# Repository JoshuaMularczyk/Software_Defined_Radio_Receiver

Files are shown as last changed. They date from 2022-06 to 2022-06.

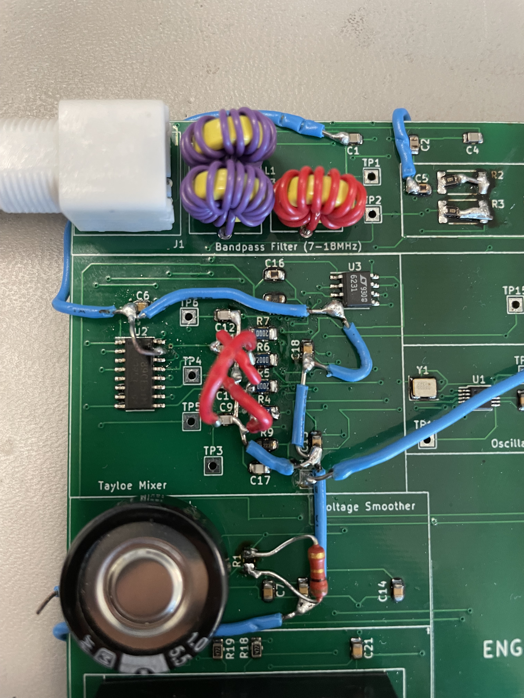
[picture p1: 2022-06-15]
Visuals/IMG-2089.jpg

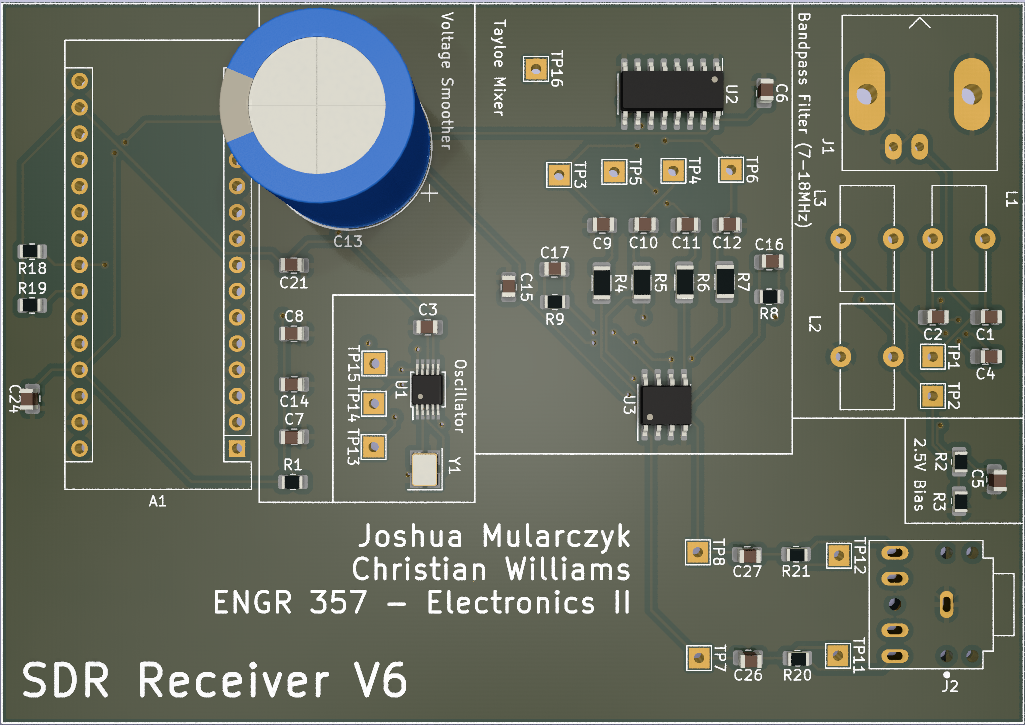
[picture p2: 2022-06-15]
Visuals/rev6pcb.PNG

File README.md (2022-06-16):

# Software-Defined-Radio-Reciever

This project was taken on with the goal to create a Software Defined Radio (SDR) in coolaboration with my partner [Christian Williams](https://github.com/cwill713). This project was completed for my Engineering Electronics II class and given to us by our professor, [Dr. Rob Frohne](https://github.com/frohro).

## Design Specifications/Objectives

These are the design specifications and objectives that my partner and I decided on. Origianlly, we decided to build a commercial FM radio, but after discusstion with Dr. Frohne, we reconsidered. The final specifications we decided on are as follows:

#### Objectives

- $25 budget
- Less than -107 dBm (1uV) minimum discernible signal
- *Stretch Goal* -127 dBm (.1uV) minimum discernible signal
- Good image rejection
- Low noise figure

#### Specs

- Frequency Range: 7MHz - 18MHz
- Radio Type: Shortwave
- One Butterworth Bandpass Filter
- One Tayloe Mixer
- One Bessel Lowpass Filter
- One Power Supply Noise Filter

## Overview

Our (SDR) receiver connects to an antenna (mounted ontop of the Engineering Building) and covers the filtering, mixing, and amplifying of the desired I and Q signals. Our I and Q signals are then passed through an external sound card and software handles the demodulation of the signal into audio. The mixing in our SDR is handled using an Arduino Nano running code provided to us by Dr. Rob Frohne which can be found in the [Arduino file](https://github.com/JoshuaMularczyk/Software_Defined_Radio_Receiver/blob/main/Arduino/New_Quisk_Nano/New_Quisk_Nano.ino). The Arduino interfaces with Quisk, an SDR that controls our receiver through the Arduino. Using Quisk, the radio can be tuned to a certain frequency by adjusting the speed of the local oscillator used in the mixing process.

## Theory

blockdia

The block diagram above shows the basic components of our SDR Receiver. The signal is received by an antenna and is passed through the bandpass filter which attenuates signals that are above or below our frequency range of 7-18 MHz. These signals are then passed through the Tayloe Quadrature Product Detector. This generates the I and Q signals for demodulation. Once the signals have been split they pass through the low noise filter which cuts off anything above 100 KHz, creating a smooth output signal. This signal is then send into an external soundcard which demodulates teh signal before it is read by Quisk software. Quisk interfaces to the Arduino Nana and allows for tuning of the desired frequency.

## Rev 6 Schematic

completeschematic

Christian and I built and tested our SDR based on the 5th Rev of this project. These schematics can be found in the Rev 5 file. The follow schematics are our most updated designs. These were created after finding multiple errors while constructing our pcb. The Rev 6 schematics can be downloaded [here](https://github.com/JoshuaMularczyk/Software_Defined_Radio_Receiver/tree/main/Schematics/SDRrecV6). These schematics were all designed in [KiCad](https://www.kicad.org/) and will be broken down into seperate pieces below.

### BandPass Filter

BandPass Filter and Voltage Divider

We built this bandpass filter using the [LC Filter Design Tool](https://rf-tools.com/lc-filter/.). This is a 3rd-Order Conventional, Series First, Butterworth Filter that will only allow frequencies between 7MHz and 18MHz to pass through it. It has input and output impedances of 50 ohms.

### Mixer and Lowpass Filter

Tayloe Mixer

The mixer that Christian and I decided to use was  Tayloe Mixer we referenced this [paper](http://www.norcalqrp.org/files/Tayloe_mixer_x3a.pdf) by Dan Tayloe when designing our mixer. The demultiplexer that we used was the [SN74CBT](http://www.ti.com/lit/gpn/sn74cbt3253) which converts the RF signal into four baseband signals. The Tayloe mixer uses switches to combine the signals that are 180 degrees out of phase with differential amplifiers so that signals above and below the oscilator frequecy can be detected.

Our Lowpass filter was designed using the [TI Filter Design Tool](). It was made using two [LT6231](https://www.analog.com/media/en/technical-documentation/data-sheets/623012fc.pdf) low noise op amps and is designed to block all frequencies greater that 100kHz.

### Voltage Smoother

Voltage Smoother

Our Voltage Smoother with take the 5V Vcc and remove as much noise as possible using a very large capacitace. Our schematic here shows the C3 having a value of 8200uF, however we ended up using a 1F capacitor that we already had in the lab. This takes the voltage that comes in from the computer and outputs a smoother 5V for the SDR to use.

### Arduino and Si5351

Arduino and Si5351

Our [Si5351](https://www.silabs.com/documents/public/data-sheets/Si5351-B.pdf) programmable oscillator allows us to input two clock signals that are 90 degrees out of phase into S0 and S1 of the SN74CBT3253. The Arduino Nano controls the frequency that is put out by the Si5351 for tuning. For our testing we had the [Aduino](http://www.mouser.com/pdfdocs/Gravitech_Arduino_Nano3_0.pdf) set the frequency to 14,190,000 Hz to match what was being output by a signal generator.

## Rev 5 Simulations

We conducted all of our simulations on [LTSpice](https://www.analog.com/en/design-center/design-tools-and-calculators/ltspice-simulator.html). My partner, Christian Williams, conducted the simulations of both filters and the Tayloe Mixer.

### Bandpass Filter

Bandpass Filter Simulation Graph
Bandpass Filter Simulation

Our Bandpass Filter was designed to allow a frequency range of 7-18MHz to pass through. As seen in the simulation above, curser 1 and cursor 2 mark the two freqency cutoff points. Inbetween them is the peak of our curve which is just where we want it.

### Lowpass Filter

LowPass Filter Simulation
LowPass Filter Schematic

### Complete SDR

Complete Simulation Graph
Complete SDR Simulation

We designed the tayloe mixer using four voltage controlled switches, and four voltage pulses that control them. For our op amps, we added our LT6231, these are already Linear Technology componenets so they dont take long to simulate in LTSpice. The LT6231's had a much lower noise profile than the LM4578's we selected for our second LPF(which we ended up removing in Rev 6), so we knew that the first LPF would take care of mostly everything and the second would just perfect the output. In the simulation window above you can see the baseband signals and the I and Q outputs. They're exactly as expected, about 90 degrees out of phase.

## Rev 6 PCB Design

rev6pcb

## Rev 5 Testing and Fixed Issues

When constructing our Rev 5 board, I ran into three issues. These issues have been fixed and closed. They are explained in detail in the issues page [here](https://github.com/JoshuaMularczyk/Software_Defined_Radio_Receiver/issues?q=is%3Aissue+is%3Aclosed)!

Luckily I was able to fix all of these mistakes with simple cutting and jumping techniques. We immediately fixed the schematics and Christian created Rev 6 of the PCB which was displayed above.

## Project Results

We first tested to see the minimum discernible signal by hooking our board up to a signal generator, our system running quisk software, and a soundcard. We adjusted the attenuator on the signal generator to output a signal of 14.19 MHz and then dropped the signal on the attenuator to see how small of a signal we could detect. In the image below, we see our radio has a minimum disernable signal of inbetween 0.3-0.4 uV!

minDecV2

We then hooked up our SDR to a BNC connector that ran to the roof of our Engineering building into an antenna. The final test was to see if we could hear any radio opperators transmitting around the world. We first looked at the signals being read in to see that our radio was picking up signals as far as Russia and Italy. Next we decided to listen in and found several bandwidths being used for communications. Here are two that we took snippets of.

The first signal that we tuned into was being used to communicate the weather from what sounded like an air traffic control tower. 

## "Wind 360 degrees, light drizzle, visibility more than 6 miles".

weather

The second was an automated message that would read off the Coordinated Universal time every minute.

## "At the tone ****** 5 hours 52 minutes coordinated universal time"

listeningIn

We were also able to listen to a few different music stations as well as two men in Hawaii talk about hurricanes to each other.

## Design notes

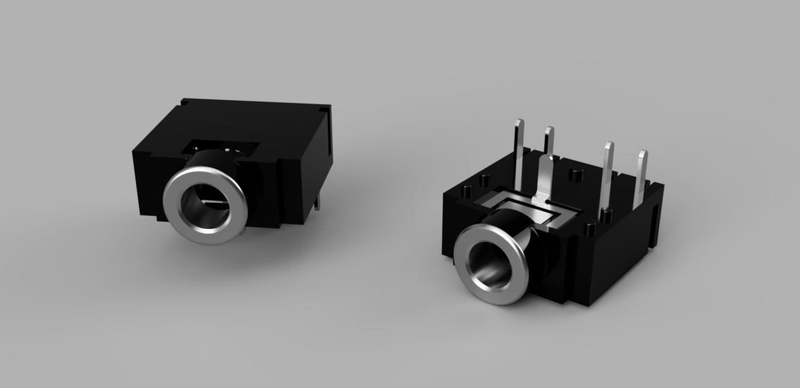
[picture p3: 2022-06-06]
Schematics/Audio Jack_Stereo 3.5mm/Audio_Jack1.png

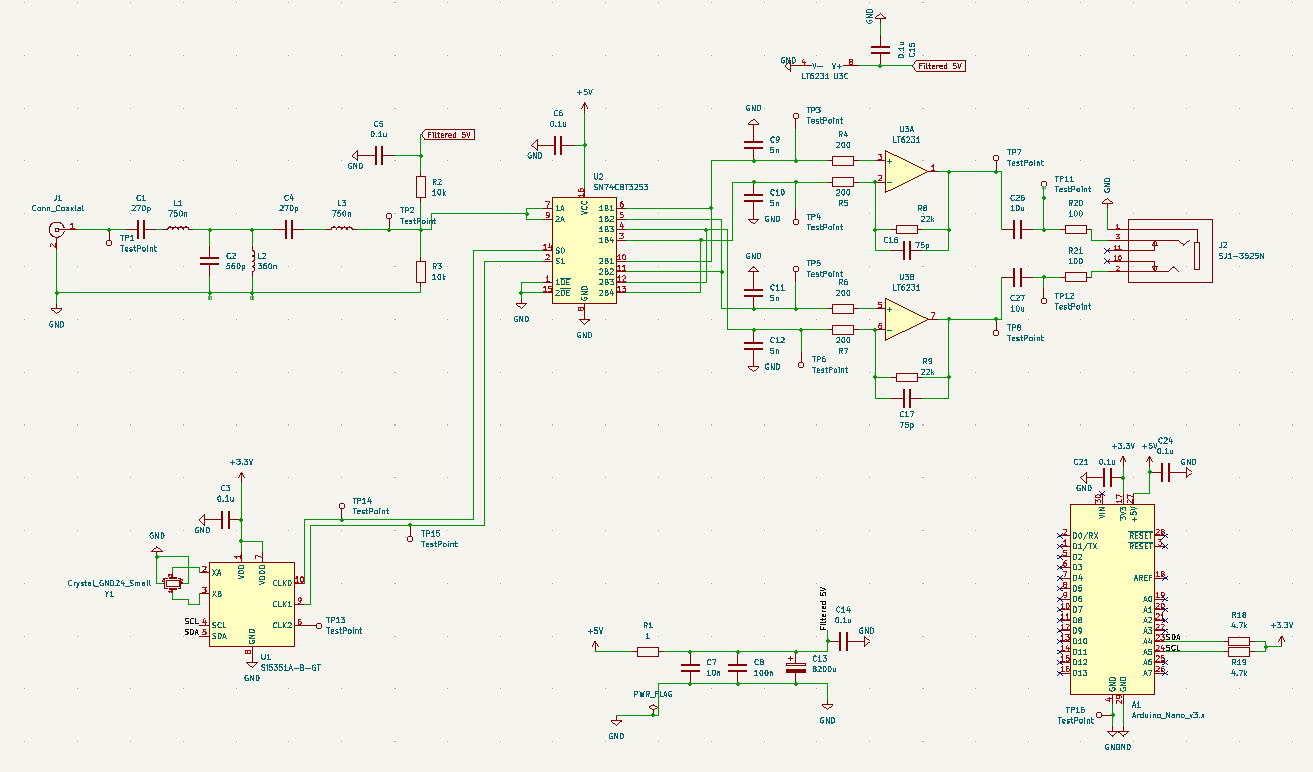
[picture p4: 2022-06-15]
Visuals/completeschematic.PNG

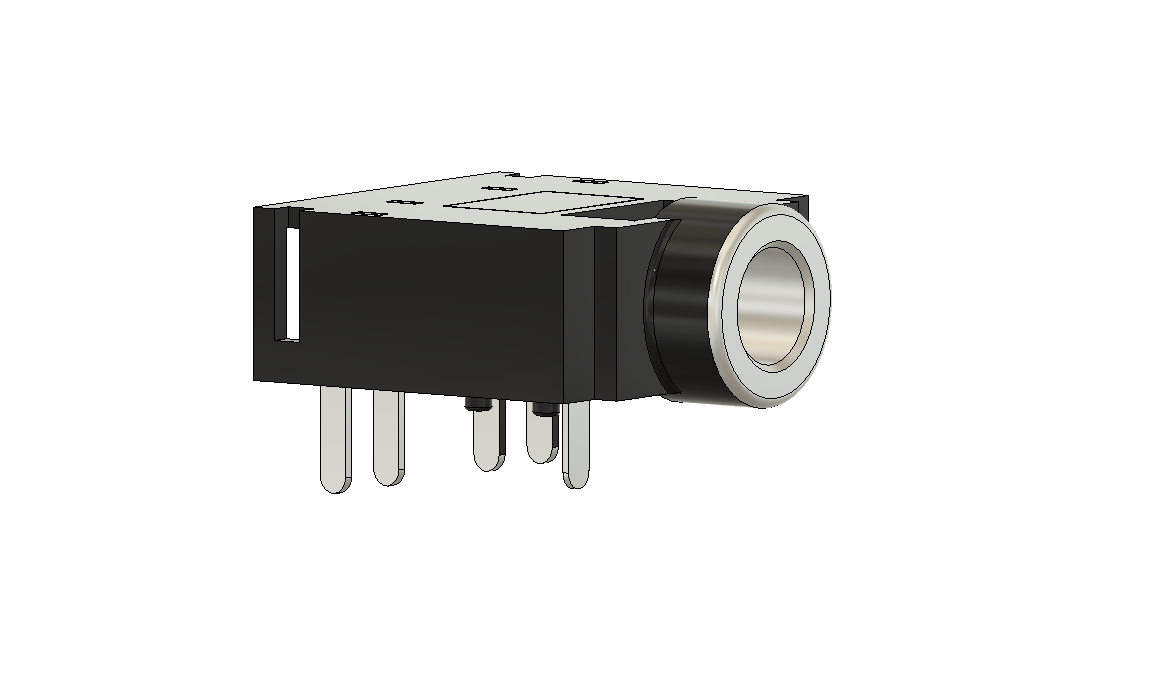
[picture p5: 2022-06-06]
Schematics/Audio Jack_Stereo 3.5mm/Audio_Jack2.png

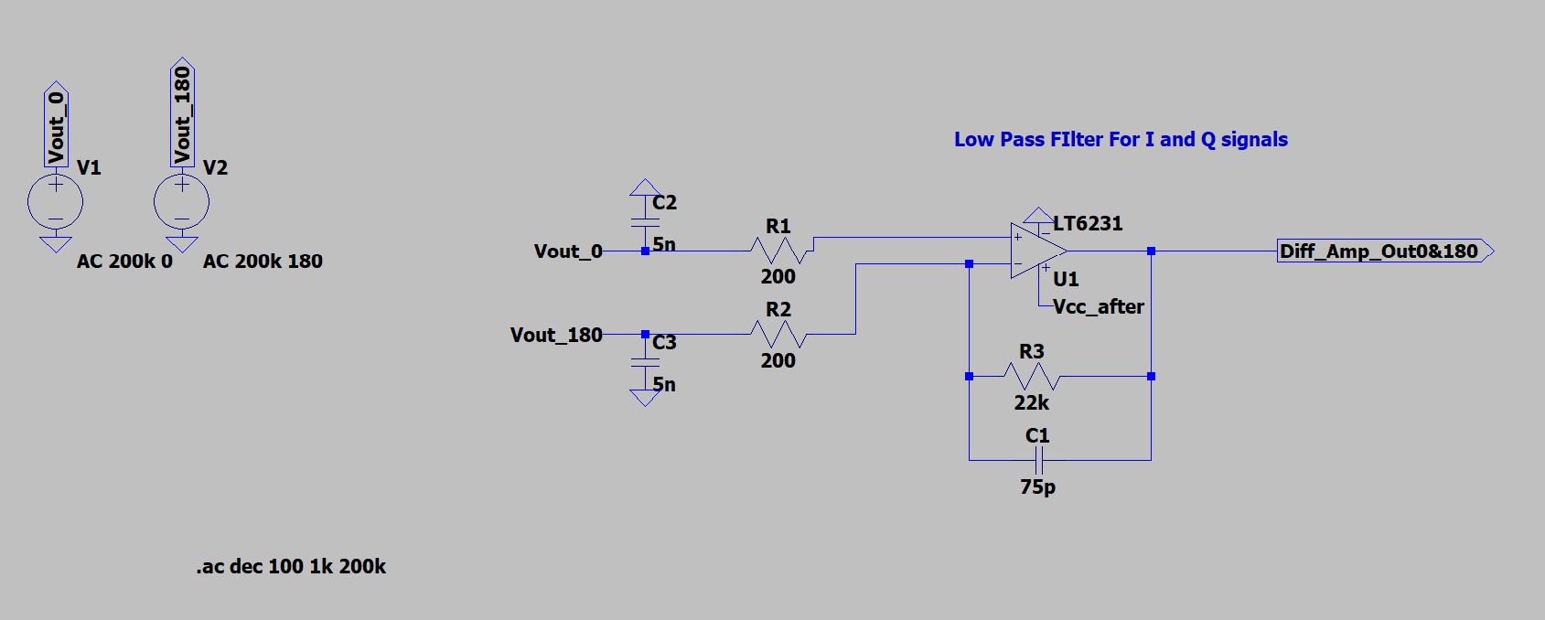
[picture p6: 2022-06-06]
Visuals/LowPass Filter Schematic.jpg

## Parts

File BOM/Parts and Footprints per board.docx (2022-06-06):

Parts and Footprints per board

2 10k Ohm resistor https://www.digikey.com/en/products/detail/cal-chip-electronics-inc/RM25J103CT/13569104 | 2512 packaging
2 270pF Capacitors https://www.digikey.com/en/products/detail/panasonic-electronic-components/ECH-U1H271GX5/353662 | Capacitor_SMD:C_0805_2012Metric
2 750nH Inductor https://www.digikey.com/en/products/detail/te-connectivity-passive-product/36502AR75JTDG/5399630 | 0805 packaging
1 560pF Capacitor https://www.digikey.com/en/products/detail/panasonic-electronic-components/ECH-U1H561GX5/353666 | Capacitor_SMD:C_0805_2012Metric
1 360nH Inductor https://www.digikey.com/en/products/detail/te-connectivity-passive-product/36502AR36JTDG/5399627 | 0805 packaging
9 .1uF Capacitors https://www.digikey.com/en/products/detail/cornell-dubilier-electronics-cde/FCA0805C104M-J2/1924083 | Capacitor_SMD:C_0805_2012Metric
1 SN74CBT3253D https://www.digikey.com/en/products/detail/texas-instruments/SN74CBT3253D/377929 | SOIC-16_3.9x9.9mm
4 5n Capacitors https://www.digikey.com/en/products/detail/murata-electronics/GRM2195C1H512JA01D/586786 | Capacitor_SMD:C_0805_2012Metric
4 200 Ohm Resistors https://www.digikey.com/en/products/detail/koa-speer-electronics-inc/RK73G2BTTD2000D/13590332 | Resistor_SMD:R_1206_3216Metric
2 22k Ohm Resistor https://www.digikey.com/en/products/detail/te-connectivity-passive-product/CRG0805F22K/2380871 | Resistor_SMD:R_0805_2012Metric
2 75pf Capacitors https://www.mouser.com/ProductDetail/Kyocera-AVX/08055A750FAT2A?qs=PcWMbIuZCschK4TeXNjJGQ%3D%3D | Capacitor_SMD:C_0805_2012Metric
2 4.64k Resistors https://www.digikey.com/en/products/detail/panasonic-electronic-components/ERJ-6ENF4641V/93079 | 0805
2 52.3k Resistors https://www.digikey.com/en/products/detail/stackpole-electronics-inc/RNCP0805FTD52K3/2240287 | Resistor_SMD:R_0805_2012Metric
4 100 pf Capacitors https://www.digikey.com/en/products/detail/panasonic-electronic-components/ECH-U1H101GX5/353657 | Capacitor_SMD:C_0805_2012Metric
2 2.49k Ohm Resistors https://www.digikey.com/en/products/detail/koa-speer-electronics-inc/RK73G2ATTD2491F/13575866 | Resistor_SMD:R_0805_2012Metric
2 17.4k Ohm Resistors https://www.digikey.com/en/products/detail/panasonic-electronic-components/ERA-6AEB1742V/2025773 | Resistor_SMD:R_0603_1608Metric
2 10uF Capacitors https://www.digikey.com/en/products/detail/samsung-electro-mechanics/CL21A106KOQNNNG/3894417 | Capacitor_SMD:C_0805_2012Metric
2 100 Ohm Resistors https://www.digikey.com/en/products/detail/koa-speer-electronics-inc/RK73G2ATTD1000D/13576043 | Resistor_SMD:R_0805_2012Metric
2 4.7k Ohm Resistors https://www.digikey.com/en/products/detail/te-connectivity-passive-product/CRGCQ0805J4K7/8576740 | Resistor_SMD:R_0805_2012Metric
1 10nF Capacitor https://www.digikey.com/en/products/detail/cornell-dubilier-electronics-cde/FCP0805C103J-J2/1924307 | Capacitor_SMD:C_0805_2012Metric
1 100nF Capacitor https://www.digikey.com/en/products/detail/cornell-dubilier-electronics-cde/FCA0805C104M-J2/1924083 | Capacitor_SMD:C_0805_2012Metric
1 10uF Polarized Capacitor https://www.digikey.com/en/products/detail/panasonic-electronic-components/EEE-FK1C100R/765952 | lmao:CAP_EEEFK1C100R
1 25MHz Crystal https://www.digikey.com/en/products/detail/kyocera-avx/CX3225SB25000D0FLJCC/6123311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 | Crystal:Crystal_SMD_3225-4Pin_3.2x2.5mm

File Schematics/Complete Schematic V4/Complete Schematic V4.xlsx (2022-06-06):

Source: | C:\Users\willi\OneDrive\Documents\Walla Walla University\Spring 2022\Electronics II\SDR GitHub\Schematic\Complete Schematic V4\Complete Schematic V4.kicad_sch
Date: | 2022-04-28 00:24
Tool: | Eeschema (6.0.4)
Generator: | C:\Program Files\KiCad\6.0\bin\scripting\plugins/bom_csv_grouped_by_value_with_fp.py
Component Count: | 73
Ref | Qnty | Value | Cmp name | Footprint | Description | Vendor
A1, | 1 | Arduino_Nano_v3.x | Arduino_Nano_v3.x | Module:Arduino_Nano | Arduino Nano v3.x
C1, C4, | 2 | 270p | C | Capacitor_SMD:C_0805_2012Metric | Unpolarized capacitor
C2, | 1 | 560p | C | Capacitor_SMD:C_0805_2012Metric | Unpolarized capacitor
C3, C5, C6, C14, C15, C18, C21, C24, C25, | 9 | 0.1u | C | Capacitor_SMD:C_0805_2012Metric | Unpolarized capacitor
C7, | 1 | 10n | C | Capacitor_SMD:C_0805_2012Metric | Unpolarized capacitor
C8, | 1 | 100n | C | Capacitor_SMD:C_0805_2012Metric | Unpolarized capacitor
C9, C10, C11, C12, | 4 | 5n | C | Capacitor_SMD:C_0805_2012Metric | Unpolarized capacitor
C13, | 1 | EEEFK1C100R | EEEFK1C100R | lmao:CAP_EEEFK1C100R
C16, C17, | 2 | 75p | C | Capacitor_SMD:C_0805_2012Metric | Unpolarized capacitor
C19, C20, C22, C23, | 4 | 100p | C | Capacitor_SMD:C_0805_2012Metric | Unpolarized capacitor
C26, C27, | 2 | 10u | C | Capacitor_SMD:C_0805_2012Metric | Unpolarized capacitor
J1, | 1 | Conn_Coaxial | Conn_Coaxial | Connector_Coaxial:BNC_Amphenol_B6252HB-NPP3G-50_Horizontal | coaxial connector (BNC, SMA, SMB, SMC, Cinch/RCA, LEMO, ...)
J2, | 1 | USB_A | USB_A | Connector_USB:USB_A_Molex_67643_Horizontal | USB Type A connector
J3, | 1 | AudioJack3 | AudioJack3 | Connector_Audio:Jack_3.5mm_CUI_SJ-3523-SMT_Horizontal | Audio Jack, 3 Poles (Stereo / TRS)
L1, L3, | 2 | 750n | L | Inductor_SMD:L_0805_2012Metric | Inductor
L2, | 1 | 360n | L | Inductor_SMD:L_0805_2012Metric | Inductor
R2, R3, | 2 | 10k | R | Resistor_SMD:R_2512_6332Metric | Resistor
R4, R5, R6, R7, | 4 | 200 | R | Resistor_SMD:R_1206_3216Metric | Resistor
R8, R9, | 2 | 22k | R | Resistor_SMD:R_2512_6332Metric | Resistor
R10, R11, | 2 | 4.64k | R | Resistor_SMD:R_0805_2012Metric | Resistor
R12, R13, | 2 | 52.3k | R | Resistor_SMD:R_0805_2012Metric | Resistor
R14, R15, | 2 | 2.49k | R | Resistor_SMD:R_0805_2012Metric | Resistor
R16, R17, | 2 | 17.4k | R | Resistor_SMD:R_0805_2012Metric | Resistor
R18, R19, | 2 | 4.7k | R | Resistor_SMD:R_0805_2012Metric | Resistor
R20, R21, | 2 | 100 | R | Resistor_SMD:R_0805_2012Metric | Resistor
TP1, TP2, TP3, TP4, TP5, TP6, TP7, TP8, TP9, TP10, TP11, TP12, | 12 | TestPoint | TestPoint |  | test point
U1, | 1 | Si5351A-B-GT | Si5351A-B-GT | Package_SO:MSOP-10_3x3mm_P0.5mm | I2C Programmable Any-Frequency CMOS Clock Generator, MSOP-8
U2, | 1 | SN74CBT3253 | SN74CBT3253 | Package_SO:SOIC-16_3.9x9.9mm_P1.27mm | Dual 1 to 4 Analog Multiplexer
U3, U4, | 2 | LT6231 | OPAMP | Package_SO:SOIC-8_3.9x4.9mm_P1.27mm | OPAmp symbol for simulation only
U5, U6, | 2 | LM4562MA | OPAMP | Package_SO:SOIC-8_3.9x4.9mm_P1.27mm | OPAmp symbol for simulation only
Y1, | 1 | Crystal | Crystal |  | Two pin crystal

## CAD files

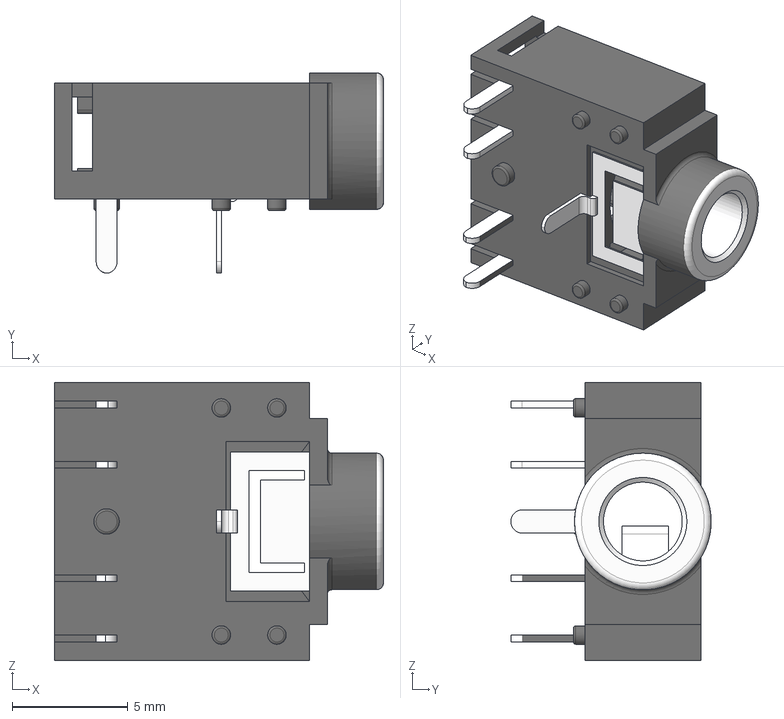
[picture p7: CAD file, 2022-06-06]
Schematics/Audio Jack_Stereo 3.5mm/Audio Jack.step
14.2 x 8.65 x 12.0 mm

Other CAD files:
Schematics/Audio Jack_Stereo 3.5mm/Audio Jack.f3d

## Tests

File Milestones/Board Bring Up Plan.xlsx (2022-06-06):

Build and Test Plan | Testers: Joshua Mularczyk and Christian Williams
Steps: | Description: | Column3 | Column4 | Column5 | Column6 | Column7 | Column8 | Column9 | Column10 | Column11 | Column12
1 | Unbox Parts/PCB and take inventory
2 | Solder everything onto pcb
3 | Test bandpass filter by using signal generator and using initial windings on inductors. Keep adjusting windings until only 7-18MHz pass through
4 | Test Clocks by putting the oscilloscope across the clock test point and ground. Program the clock to what it needs to be and measure the frequency. Make sure there is a 90 degreee phase shift.
5 | Test the 4 points outputted from the Tayloe Mixer and make sure the top two inputs are 180 degrees apart and the bottom two are 180 degrees apart.
6 | Use the test point at the output of the second lowpass filter to make sure that only 100 KHz are entering the soundcard.
7 | After these main tests, check each test point to make sure values correspond with the simulated or expected values.
8 | Run the program and see if everything works
9 | Once the SDR is working with the signal generator, take the SDR up and connect it to the antenna.
10

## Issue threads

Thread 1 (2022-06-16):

Missing ground plane on Rev 5 pcb

JoshuaMularczyk, 2022-06-16:
When our Rev 5 boards arrived we realized that there was no ground plane. I had accidentally clicked off the ground plane right before generating the Gerber files, so no ground plane was present. To fix this, I went ahead and connected any ground connections that relied on the ground plane with external wires. This can be seen in the [Rev 5 photos on the wiki](https://github.com/JoshuaMularczyk/Software_Defined_Radio_Receiver/wiki/Rev-5-Photos).

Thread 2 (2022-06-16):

Tayloe Mixer connection (wrong order)

JoshuaMularczyk, 2022-06-16:
Next, a fellow classmate, [Nicholas Zimmerman](https://github.com/nickz12345), who had been helping us error check, noticed that we had wired our Tayloe Mixer incorrectly. We had connected our outputs across to the amplifiers in ascending order (1,2,3,4) when they were actually supposed to be connected in the following order (1,4,2,3). I then cut the last three out of the four traces and jumped the wires to send the I and Q signals to the correct paths. This can also be seen in the [wiki](https://github.com/JoshuaMularczyk/Software_Defined_Radio_Receiver/wiki/Rev-5-Photos).

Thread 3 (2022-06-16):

Second Low Pass Filter Error

JoshuaMularczyk, 2022-06-16:
This error was for our Rev 5 design and was found in our second low pass filter. This was discovered by [Dr. Rob Frohne](). We had not realized that the V- needed to be connected to a negative voltage instead of ground. Luckily this was a backup filter and most of the gain was in our first LPF. To fix this, I simply just removed the second LPF from the board and jumped the outputs of the first LPF to the inputs of the capacitors right before our audio connector.

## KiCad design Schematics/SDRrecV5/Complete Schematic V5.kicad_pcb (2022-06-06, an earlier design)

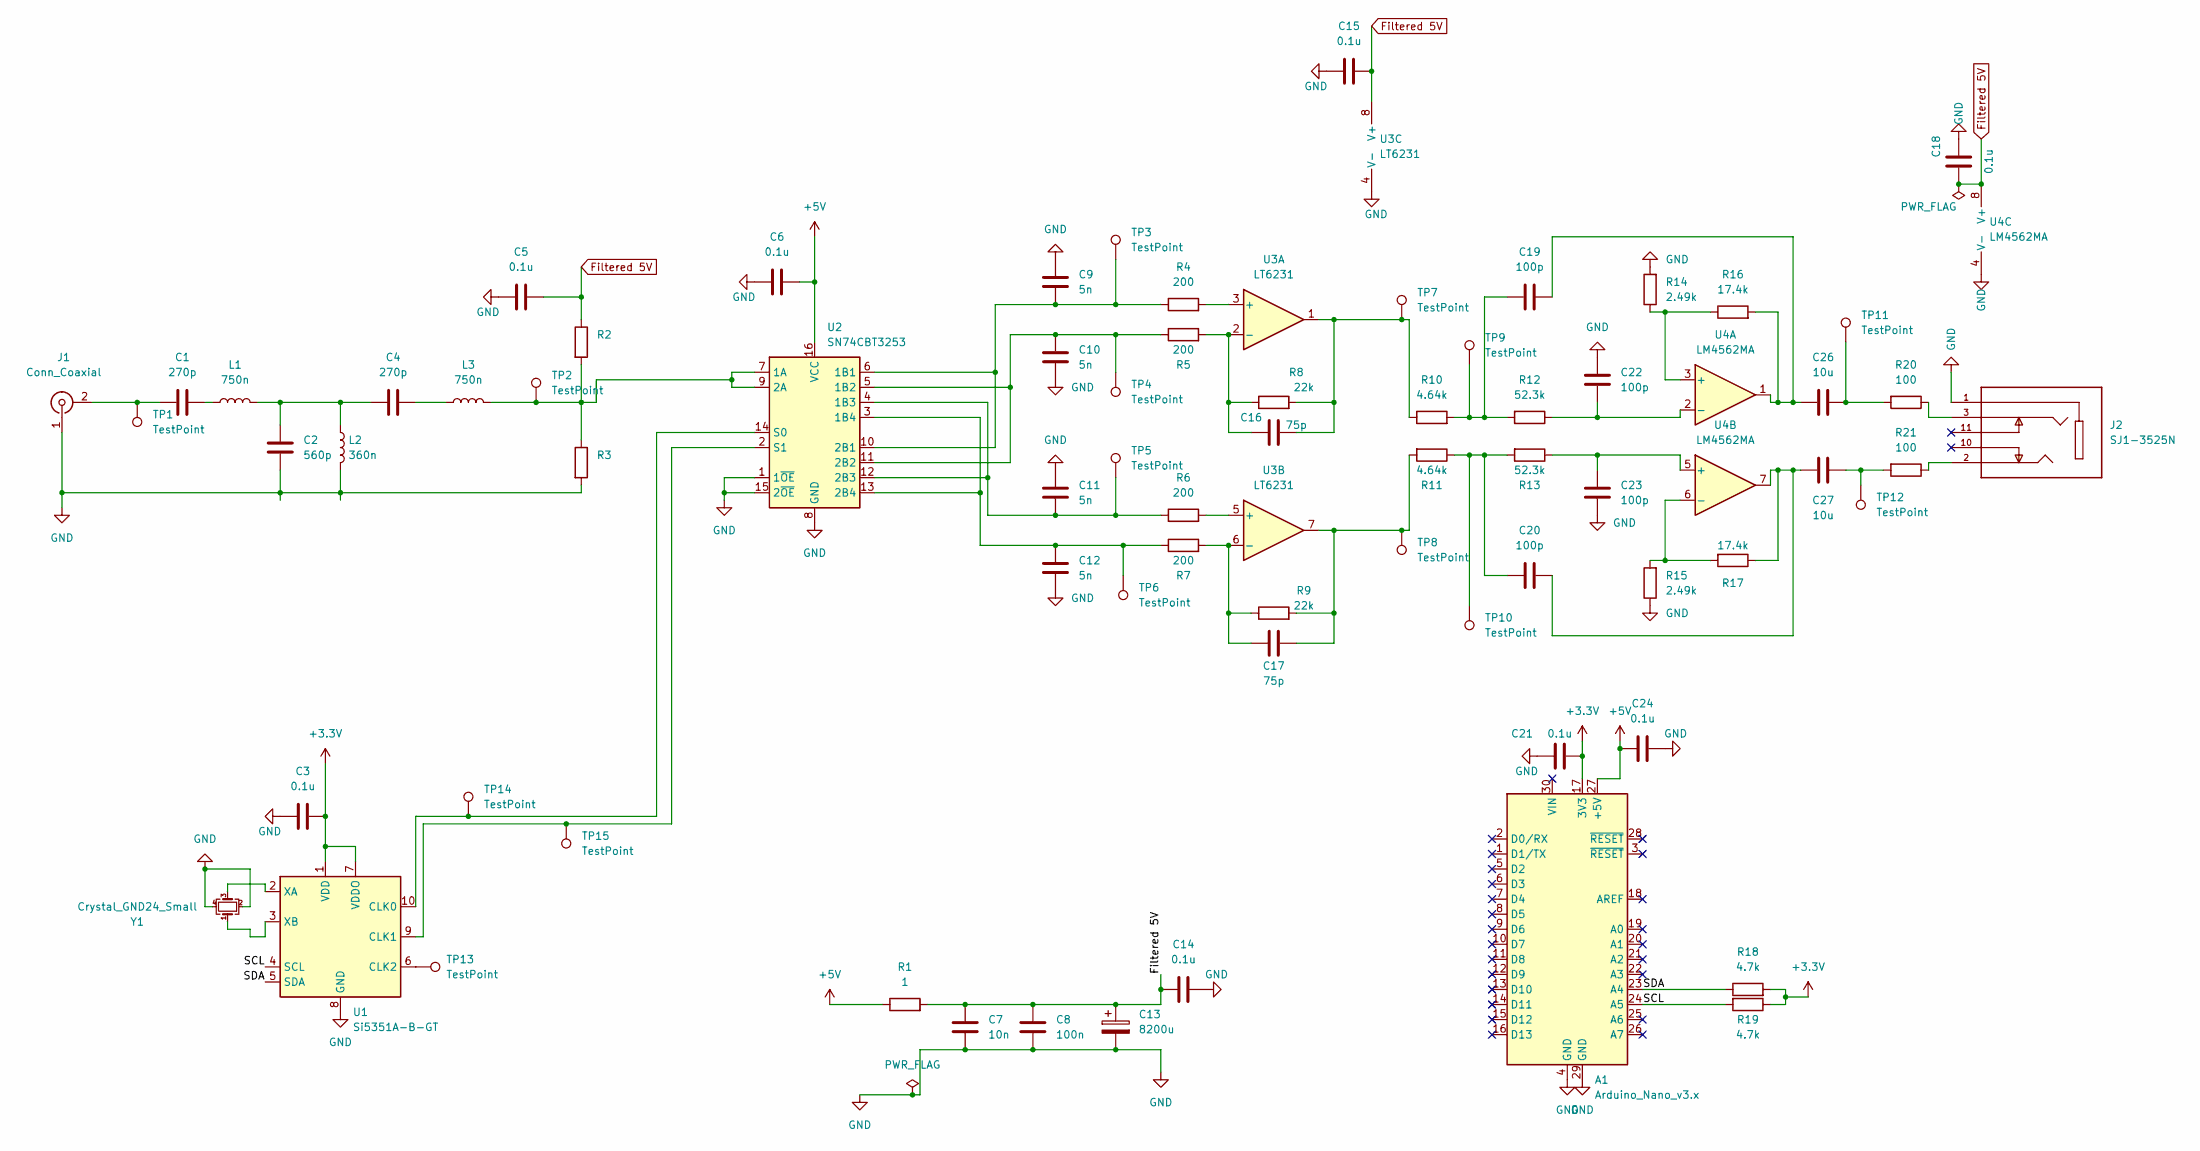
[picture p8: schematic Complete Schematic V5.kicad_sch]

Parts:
A1: Arduino_Nano_v3.x; Arduino_Nano
C1, C4: 270p; C_0805_2012Metric
C2: 560p; C_0805_2012Metric
C3, C5, C6, C14, C15, C18, C21, C24: 0.1u; C_0805_2012Metric
C7: 10n; C_0805_2012Metric
C8: 100n; C_0805_2012Metric
C9, C10, C11, C12: 5n; C_0805_2012Metric
C13: 8200u; CP_Radial_D16.0mm_P7.50mm
C16, C17: 75p; C_0805_2012Metric
C19, C20, C22, C23: 100p; C_0805_2012Metric
C26, C27: 10u; C_0805_2012Metric
J1: Conn_Coaxial; BNC_Amphenol_B6252HB-NPP3G-50_Horizontal
J2: SJ1-3525N; Jack_3.5mm_stereo_TRS_jack; PARTREV 1.02
L1, L3: 750n; L_Toroid_Vertical_L10.0mm_W5.0mm_P5.08mm
L2: 360n; L_Toroid_Vertical_L10.0mm_W5.0mm_P5.08mm
R1: 1; R_0805_2012Metric
R2, R3: (no value)
R4, R5, R6, R7: 200; R_1206_3216Metric
R8, R9: 22k; R_0805_2012Metric
R10, R11: 4.64k; R_0805_2012Metric
R12, R13: 52.3k; R_0805_2012Metric
R14, R15: 2.49k; R_0805_2012Metric
R16, R17: 17.4k; R_0805_2012Metric
R18, R19: 4.7k; R_0805_2012Metric
R20, R21: 100; R_0805_2012Metric
TP1, TP2, TP3, TP4, TP5, TP6, TP7, TP8, TP9, TP10, TP11, TP12, TP13, TP14, TP15: TestPoint; TestPoint_THTPad_2.0x2.0mm_Drill1.0mm
U1: Si5351A-B-GT; MSOP-10_3x3mm_P0.5mm
U2: SN74CBT3253; SOIC-16_3.9x9.9mm_P1.27mm
U3: LT6231; SOIC-8_3.9x4.9mm_P1.27mm
U4: LM4562MA; SOIC-8_3.9x4.9mm_P1.27mm
Y1: Crystal_GND24_Small; Crystal_SMD_3225-4Pin_3.2x2.5mm

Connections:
+3V3: A1.17 (3V3), C3.2, C21.2, R18.2, R19.1, U1.1 (VDD), U1.7 (VDDO)
+5V: A1.27 (+5V), C6.2, C24.2, R1.1, U2.16 (VCC)
/SCL: A1.24 (A5), R19.2, U1.4 (SCL)
/SDA: A1.23 (A4), R18.1, U1.5 (SDA)
Filtered 5V: C5.2, C7.1, C8.1, C13.1, C14.2, C15.2, C18.2, R1.2, R2.1, U3.8 (V+), U4.8 (V+); also elsewhere on the board
GND: A1.4 (GND), A1.29 (GND), C2.2, C3.1, C5.1, C6.1, C7.2, C8.2, C9.2, C10.1, C11.2, C12.1, C13.2, C14.1, C15.1, C18.1, C21.1, C22.2, C23.1, C24.1, J1.1 (In), J2.1, L2.2, R3.2, R14.2, R15.1, U1.8 (GND), U2.1 (1~OE), U2.8 (GND), U2.15 (2~OE), U3.4 (V-), U4.4 (V-), Y1.2, Y1.4; also elsewhere on the board
unnamed: C1.1, L1.1
unnamed: C1.2, J1.2 (Ext), TP1.1
unnamed: C2.1, C4.1, L1.2, L2.1
unnamed: C4.2, L3.1
unnamed: C9.1, R4.1, TP3.1, U2.6 (1B1), U2.10 (2B1)
unnamed: C10.2, R5.1, TP4.1, U2.5 (1B2), U2.11 (2B2)
unnamed: C11.1, R6.1, TP5.1, U2.4 (1B3), U2.12 (2B3)
unnamed: C12.2, R7.1, TP6.1, U2.3 (1B4), U2.13 (2B4)
unnamed: C16.1, R8.2, R10.1, TP7.1, U3.1
unnamed: C16.2, R5.2, R8.1, U3.2 (-)
unnamed: C17.1, R9.2, R11.2, TP8.1, U3.7
unnamed: C17.2, R7.2, R9.1, U3.6 (-)
unnamed: C19.1, R10.2, R12.2, TP9.1
unnamed: C19.2, C26.2, R16.2, U4.1
unnamed: C20.1, R11.1, R13.2, TP10.1
unnamed: C20.2, C27.2, R17.1, U4.7
unnamed: C22.1, R12.1, U4.2 (-)
unnamed: C23.2, R13.1, U4.5 (+)
unnamed: C26.1, R20.2, TP11.1
unnamed: C27.1, R21.2, TP12.1
unnamed: J2.2, R21.1
unnamed: J2.3, R20.1
unnamed: L3.2, R2.2, R3.1, TP2.1, U2.7 (1A), U2.9 (2A)
unnamed: R4.2, U3.3 (+)
unnamed: R6.2, U3.5 (+)
unnamed: R14.1, R16.1, U4.3 (+)
unnamed: R15.2, R17.2, U4.6 (-)
unnamed: TP13.1, U1.6 (CLK2)
unnamed: TP14.1, U1.10 (CLK0), U2.14 (S0)
unnamed: TP15.1, U1.9 (CLK1), U2.2 (S1)
unnamed: U1.2 (XA), Y1.3
unnamed: U1.3 (XB), Y1.1

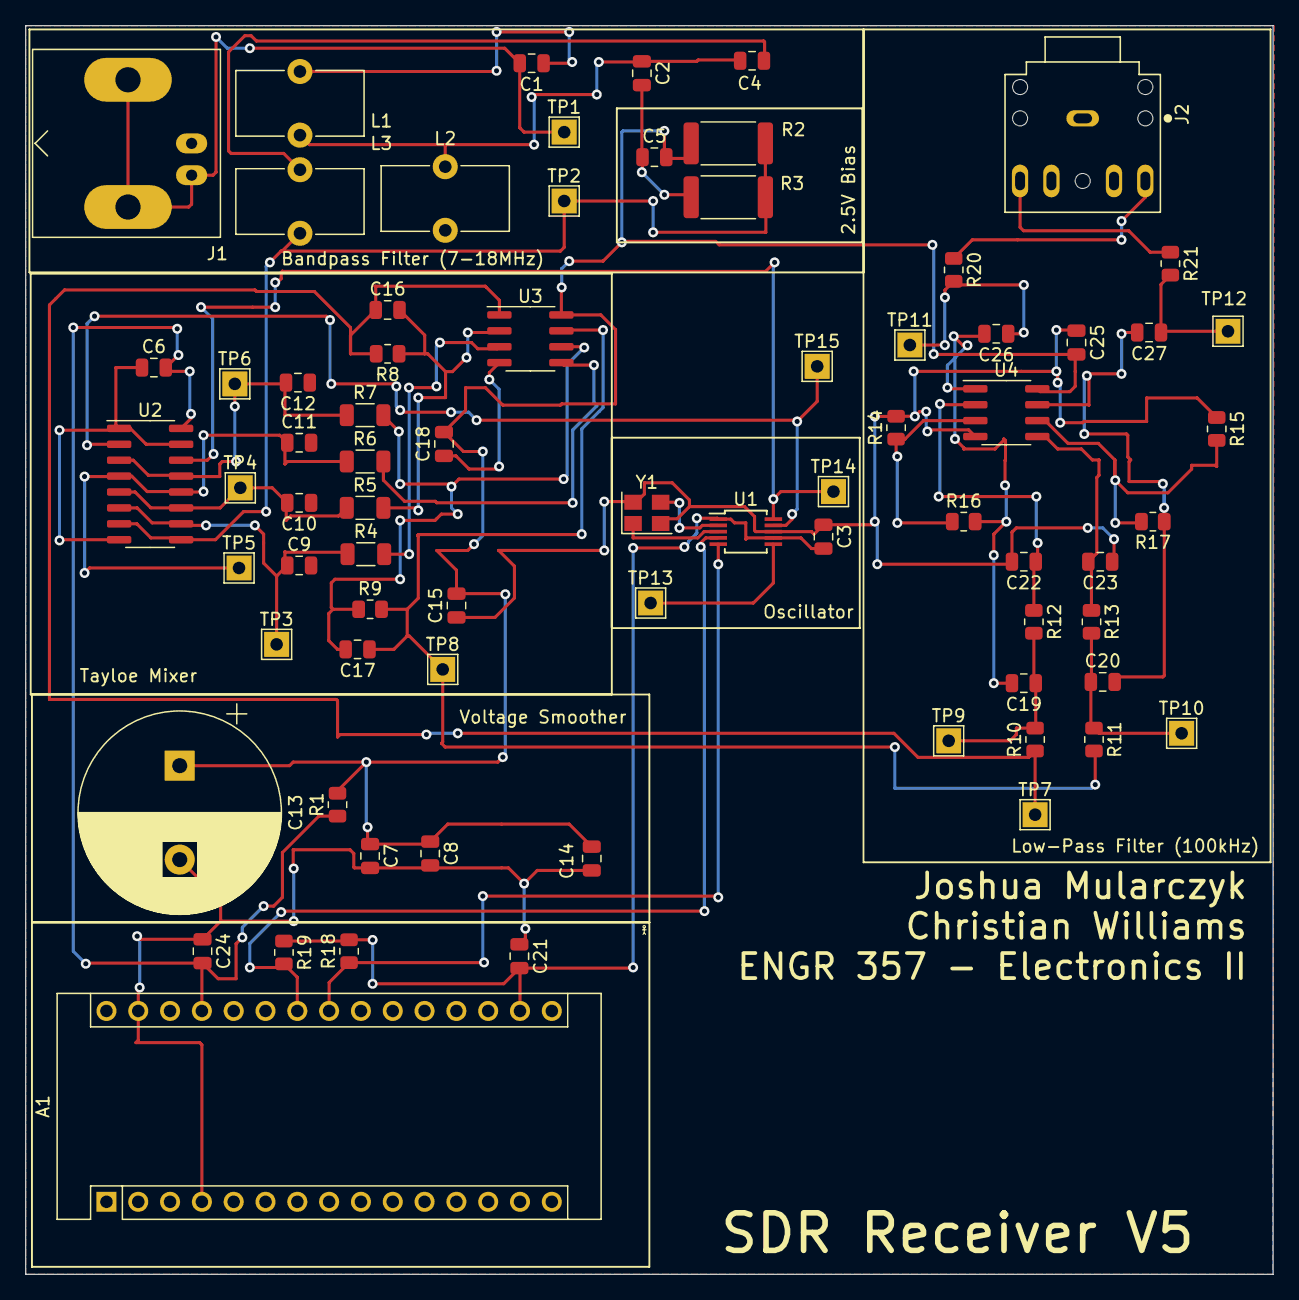
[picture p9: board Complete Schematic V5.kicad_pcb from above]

Board: 2 copper layers, 99.6 x 99.7 mm, 74 parts (0 on the bottom side), 38 nets.

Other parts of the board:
C25: 0.1u; C_0805_2012Metric

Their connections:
Filtered 5V: C25.2; also elsewhere on the board
GND: C25.1; also elsewhere on the board

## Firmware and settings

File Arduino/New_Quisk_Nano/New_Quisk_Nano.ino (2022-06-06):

#include <si5351.h>

#include <si5351.h>


/*
  OpenRadio Quisk Interface 
  Main
  This is used to provide a serial interface which Quisk SDR can talk to.
  
  Copyright (C) 2014 Mark Jessop <vk5qi@rfhead.net>

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
    For a full copy of the GNU General Public License, 
    see <http://www.gnu.org/licenses/>.

   Command Reference:
    ------------------
    All commands consist of an identifier, followed by one or more parameters delinieated by commas, then a newline.
    i.e.:
    COMMAND,<param1>,<param2><LF>
    
    A command will return OK<LF> if successful, and ERROR<LF> if not. Some commands (particuarly transmit commands)
    may take a significant amount of time to return.
    
    Sending a command which takes parameters, without sending the parameters, will return the set parameters.
    
    Frequency Settings:
    
    FREQ,<freq>     - Set the center freq of the receiver, in Hz.
    FREQPSK,<freq>    - Set the transmit frequency, in Hz.

    Modulation:
    All transmissions will time out after 10 minutes. (if we implement it)
    
    CARRIER,<ON/OFF>  - Transmit a carrier.
    PSK,<rate>,message  - Send message using Phase Shift Keying, with the specified symbol rate.

    This version is made for the Rasbperry Pi Pico using the MBED OS..
*/

#include <Arduino.h>

//#warning __PGMSPACE_H_

//#include <EEPROM.h>
#include <Wire.h>

#include "si5351.h"

#include "settings.h"
#include "pins.h"
//#include "ring_buffer.h"

#define VERSION "0.3"

// #define USE_JOHNSON_COUNTER
// Default output frequency
#define RX_FREQ 14200000
#define TX_FREQ 14200000
#define FREQ_LIMIT_LOWER 100000
#define FREQ_LIMIT_UPPER 30000000 

#define SERIAL_BAUD     57600

Si5351 si5351;

uint8_t si5351_init();
int parseFreq(String input);
int parseCarrier(String carrier_str);
int set_channel(String input);

int tx_relay_state = 0;
int tx_state = 0;

static struct settings settings;

// Ring buffer for use with the interrupt-driven transmit buffer.
//struct ring_buffer data_tx_buffer = { { 0 }, 0, 0};

/* Returns true if settings are valid */
//static bool read_settings(void)
//{
//    uint8_t *p = (uint8_t *)&settings;
//    int i = 0;
//
//    while(i < sizeof(struct settings))
//        *p++ = EEPROM.read(i++);
//
//    return settings.magic == SETTINGS_MAGIC;
//}

//static void write_settings(void)
//{
//    uint8_t *p = (uint8_t *)&settings;
//    int i = 0;
//
//    // Invalidate checksum to guard against partial writes
//    EEPROM.write(0, 0);
//
//    while(i < sizeof(struct settings))
//        EEPROM.write(i++, *p++);
//}

// Input buffer for reading user input.
#define INPUTBUFLEN 64
//char inputBuffer[INPUTBUFLEN];
int inputBufferPtr = 0;
char tempBuffer[20]; // Buffer for string to int conversion.
String inputBuffer = "";

void setup(){
    // Initialise things.
    pinMode(TX_RX_SWITCH, OUTPUT);
    digitalWrite(TX_RX_SWITCH, LOW);
    pinMode(MODULATION, OUTPUT);
    digitalWrite(MODULATION, LOW);
    pinMode(LED, OUTPUT);
    digitalWrite(LED, LOW);

    Serial.begin(SERIAL_BAUD);
    Serial.setTimeout(1000 * 10);

    uint8_t rev_id = si5351_init();

    // Click the relay as an 'audible' startup indicator.
    digitalWrite(TX_RX_SWITCH, HIGH);
    delay(300);
    digitalWrite(TX_RX_SWITCH, LOW);



// Perform Si5351 calibration
    uint64_t rx_freq = 1000024200ULL;  // Where you receive WWV before calibration...
    uint64_t target_freq = 1000000000ULL; // 10 MHz, in hundredths of hertz
    uint32_t cal_factor = (int32_t)(target_freq - rx_freq);
    si5351.set_correction(cal_factor, SI5351_PLL_INPUT_XO);
    si5351.set_pll(SI5351_PLL_FIXED, SI5351_PLLA);
    si5351.pll_reset(SI5351_PLLA);

   //    if (!read_settings()) {
        //Serial.println(F("Resetting settings to defaults"));
        settings.magic = SETTINGS_MAGIC;
        settings.rx_freq = RX_FREQ;
        settings.tx_freq = TX_FREQ;
        settings.cal_factor = cal_factor;
//    }
    
    set_rx_freq(settings.rx_freq);
    set_tx_freq(settings.tx_freq);
}

void loop(){
  if(Serial.available()){
    // Read in a byte.
    char inChar = (char)Serial.read();
    
    // Work out what the character is. If letters or numbers, add to
    // the buffer, if not, don't add.
    
    // If character is a newline, we have reached the end of the command.
    if( (inChar == '\n') || (inputBufferPtr>INPUTBUFLEN)){
      // Parse string
      if( parseCommand(inputBuffer)==0 ){
        Serial.println("OK");
      }else{
        Serial.println("ERROR");
      }
      inputBuffer = "";
      inputBufferPtr = 0;
    }else if( isalnum(inChar) || ispunct(inChar) || isblank(inChar) || inChar==4 ){
      // Add to the input buffer if printable and not a line ending.
      inputBuffer += inChar;
      inputBufferPtr++;
    }
  }
}

// CSV parser function. Splits input into arguments.
// I am so sorry...
int parseCommand(String input){
  int params = 0;
  
  if(input.length()<3){
    // No command is shorter than 3 characters. Error.
    return 1;
  }
  // At this point we have found some sort of command (maybe)
  

  // Search through for commas, populate an array of pointers, make pointer = -1 if nothing found.
  // NOTE: This is a horrible bit of code. If theres is a better way to do CSV parsing in Arduino, let me know!
  int separators[] = {-1,-1,-1,-1,-1,-1};

  separators[0] = input.indexOf(",");
  
  if(separators[0] != -1){ // If we find one comma, maybe there are more...
    int i = 1;
    while((separators[i-1] != -1) && i<6){
      params++;
      separators[i] = input.indexOf(",", separators[i-1]+1);
      i++;
    }
  
  }

  if(params==0){ // Either a request command or a command with no parameter
    if(input.startsWith("FREQPSK")){
      Serial.print("FREQPSK,"); Serial.println(settings.tx_freq);
      return 0;
    }else 
    if(input.startsWith("FREQ")){
      Serial.print("FREQ,"); Serial.println(settings.rx_freq);
      return 0;
    }else if(input.startsWith("CAL")){
      Serial.print("CAL,"); Serial.println(settings.cal_factor,10);
      return 0;
    }else if(input.startsWith("VER")){
      Serial.print("VER,"); Serial.println("OpenRadio V1.1");
      return 0;
    }else{
      // No other commands are valid without parameters. Error
      return 1;
    }
  }else if(params==1){ // Commands with one argument.
    String param1 = input.substring(separators[0]+1); // Extract the argument for passing to the function.
    if(input.startsWith("FREQPSK")){
//      return parsePSKFreq(param1);
    }else if(input.startsWith("FREQ")){
      return parseFreq(param1);
    }
    else if(input.startsWith("PSKFREQ")){
//      return parsePSKFreq(param1);
    }else if(input.startsWith("CARRIER")){
      return parseCarrier(param1);
    }else if(input.startsWith("CHAN")){
      return set_channel(param1);
    }else{
      // No other commands are valid with only one parameter. Error
      return 1;
    }
  }
//  else if(params==2){ // Commands with 2 parameters (PSK);
//    String param1 = input.substring(separators[0]+1, separators[1]);
//    String param2 = input.substring(separators[1]+1);
//    
//    if(input.startsWith("PSK")){
//      return psk_transmit(param1,param2);
//    }else{
//      // No other commands are valid with only one parameter. Error
//      return 1;
//    }
//  }

  return 1; // Cannot parse command, error.
}

int freqValid(uint32_t freq){
  return (freq>FREQ_LIMIT_LOWER) && (freq<FREQ_LIMIT_UPPER);
}

// Parse frequency, program radio.
int parseFreq(String input){
  unsigned long result = 0;
  unsigned long combinedresult = 0;
  char* endptr;
  
  input.toCharArray(tempBuffer,10);
  
  result = strtoul(tempBuffer,&endptr,10);
  // If strtoul fails to convert, *endptr contains the character which conversion failed on.
  // Otherwise, *endptr contains '\0'.
  if(*endptr != 0) return -1;
  
  if(freqValid(result)){
    set_rx_freq(result);
    Serial.print("FREQ,");Serial.println(result);
    return 0;
  }else{
    //Serial.println("Invalid input.");
    return -1;
  } 
}

// Carrier on/off
// This should transmit a carrier at an offset from the rx freq.
// We probably dont need this right now.
int parseCarrier(String carrier_str){
// TODO
  return -1;
}

// Transit a string of PSK (message) at (rate) baud.
// We need to figure out how to decide what the 'offset' from the RF freq is.
// Maybe add another command to set this?
int parsePSK(String rate, String message){
// TODO
  return -1;
}

// Set the frequency of the transmitted PSK signal.
// This is entirely independent of the receive chain, and we should
// be controlling if we want to lock this to within the RX passband 
// from within the client software.
int parsePSKFreq(String input){
  unsigned long result = 0;
  unsigned long combinedresult = 0;
  char* endptr;
  
  input.toCharArray(tempBuffer,10);
  
  result = strtoul(tempBuffer,&endptr,10);
  // If strtoul fails to convert, *endptr contains the character which conversion failed on.
  // Otherwise, *endptr contains '\0'.
  if(*endptr != 0) return -1;
  
  if(freqValid(result)){
    set_tx_freq(result);
    Serial.print("FREQPSK,");Serial.println(result);
    return 0;
  }else{
    //Serial.println("Invalid input.");
    return -1;
  } 

}


//
// Si5351 Helper Functions
//

uint8_t si5351_init(){
    si5351.init(SI5351_CRYSTAL_LOAD_8PF,0,0);
    si5351.set_pll(SI5351_PLL_FIXED, SI5351_PLLA);
    // Set output frequencies
    set_rx_freq(RX_FREQ);
    set_tx_freq(TX_FREQ);

    // Enable RX, and disable TX by default.
    si5351.output_enable(RX_CLOCK,1);
    si5351.output_enable(TX_CLOCK,0);
    si5351.output_enable(SPARE_CLOCK,0);

    // Read the status register and return the chip revision ID.
    si5351.update_status();
    return si5351.dev_status.REVID;

}

static void set_rx_freq(uint32_t freq)
{
    // Save actual value
    settings.rx_freq = freq;

#ifdef USE_JOHNSON_COUNTER
    // This is for models where quadrature mixer requires a 4X LO signal.
    si5351.set_freq(freq * 4, RX_CLOCK);
#else
 // This is for models that use the Si5351 to produce the I/Q on CLK0 and CLK1.
  uint64_t pll_freq;
  uint_fast8_t mult;
  // mult must be less than 128 (7 bits) according to documentation
  if (freq >= 26470588){
    mult = 22;
  } else if (freq >= 18000000) {
    mult = 34;
  } else if(freq > 12000000) {
    Serial.println("in the right multiplier.");
    mult = 50;
  } else if (freq >= 8000000) {
    mult = 75;
  } else if (freq > 5357143) {
    mult = 112;
  } else {
    mult = 128;
  }
  freq = (uint64_t) (freq*100ULL);
  pll_freq = (uint64_t)mult*freq;
  si5351.set_freq_manual(freq, pll_freq, SI5351_CLK0);
  si5351.set_freq_manual(freq, pll_freq, SI5351_CLK1);
  // Now we can set CLK1 to have a 90 deg phase shift by entering
  // mult in the CLK1 phase register, since the ratio of the PLL to
  // the clock frequency is mult.
  si5351.set_phase(SI5351_CLK0, 0);
  si5351.set_phase(SI5351_CLK1, mult);
  // We need to reset the PLL before they will be in phase alignment
  si5351.pll_reset(SI5351_PLLA);
#endif
if (freq <= 4.0e6){  // Set the band for the RX filters on the IQ_SDR
    digitalWrite(4, HIGH);
    digitalWrite(5, HIGH);
    }
if ((freq <= 8.0e6)&&(freq > 4.0e6)){
    digitalWrite(4, LOW);
    digitalWrite(5, HIGH);
    }
if ((freq <= 16.0e6)&&(freq > 8.0e6)){
    digitalWrite(4, HIGH);
    digitalWrite(5, LOW);
    }
else {
    digitalWrite(4, LOW);
    digitalWrite(5, LOW);
    }       
}

static void set_tx_freq(uint32_t freq)
{
    // Save actual value
    settings.tx_freq = freq;

    // Let driver choose PLL settings. May glitch when changing frequencies.
    si5351.set_freq(freq, (si5351_clock)0);
}

void tx_enable(){
    si5351.output_enable(TX_CLOCK,1);
    tx_state = 1;
}

void tx_disable(){
    si5351.output_enable(TX_CLOCK,0);
    tx_state = 0;
}

void tx(){
    digitalWrite(TX_RX_SWITCH, HIGH);
    digitalWrite(LED, HIGH);
    tx_relay_state = 1;
}

void rx(){
    digitalWrite(TX_RX_SWITCH, LOW);
    digitalWrite(LED, LOW);
    tx_relay_state = 0;
}

#define MIN_CHANNEL 1
#define MAX_CHANNEL 30


#ifdef USE_FLASH
// From https://docs.google.com/spreadsheets/d/1KP5XsAHPCD2FsUW5RoqCfCJYRt2o03q6RN2TroPgEKk/edit#gid=0
const prog_uint16_t channel_list[] =
#else
const uint16_t channel_list[] =
#endif
        {8986, 8990, 8993, 8996, 9000, 9003, 9006, 9010, 9013, 9016, 9020, 9023, 9026,
        9030, 9033, 9036, 9040, 9043, 9046, 9050, 9053, 9056, 9060, 9063, 9066, 9070,
        9073, 9076, 9080, 9083};

int set_channel(String input)
{
  unsigned long chan = 0;
  char* endptr;
  
  input.toCharArray(tempBuffer,10);
  
  chan = strtoul(tempBuffer,&endptr,10);
  // If strtoul fails to convert, *endptr contains the character which conversion failed on.
  // Otherwise, *endptr contains '\0'.
  if(*endptr != 0) return -1;



    if (chan < MIN_CHANNEL || chan > MAX_CHANNEL) {
        return 1;
    }

#ifdef USE_FLASH
    uint32_t rx = (uint32_t)pgm_read_word_near(channel_list + chan-1) * 1000;
#else
    uint32_t rx = (uint32_t)channel_list[chan-1] * 1000;
#endif
    uint32_t tx = rx * 3 + 1500;

    set_rx_freq(rx);
    set_tx_freq(tx);

    // Save settings
//    write_settings();

    Serial.print("CHAN,"); Serial.println(chan);
    return 0;
}

//int psk_transmit(String param1, String param2){
//  unsigned long baud_rate = 0;
//  char* endptr;
//  
//  param1.toCharArray(tempBuffer,10);
//  
//  baud_rate = strtoul(tempBuffer,&endptr,10);
//  // If strtoul fails to convert, *endptr contains the character which conversion failed on.
//  // Otherwise, *endptr contains '\0'.
//  if(*endptr != 0) return -1;
//
//    tx();
//    tx_enable();
//    if (!bpsk_start(baud_rate)){
//      tx_disable();
//      rx();
//        return 1;
//    }
//    delay(300); //  Short delay for RX sync to occur.
//    // Push string into ring buffer for transmission.
//    for(int i = 0; i<param2.length(); i++){
//      store_char(param2.charAt(i),&data_tx_buffer);
//    }
//    // Send an EOT control character, then a newline, to signify the end of the message.
//    store_char((char)4, &data_tx_buffer);
//    store_char('\n', &data_tx_buffer);
//    while(data_waiting(&data_tx_buffer)>0){}
//    delay(300);
//    bpsk_stop();
//    tx_disable();
//    rx();
//
//    return 0;
//}

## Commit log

2022-04-19 Upload of LowPass Filter LTSpice sim
2022-04-19 Upload of seperate part schematics from KiCad
    [LowPass Filter.kicad_pcb, LowPass Filter.kicad_sch, RF Filter.kicad_pcb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]
2022-06-06 Complete upload of all project files
    [Arduino and Si5354.kicad_sch, Audio Jack.f3d, Audio Jack.step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]
2022-06-06 Clean up of files
    [Arduino and Si5354.kicad_sch, Audio Jack.f3d, Audio Jack.step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]

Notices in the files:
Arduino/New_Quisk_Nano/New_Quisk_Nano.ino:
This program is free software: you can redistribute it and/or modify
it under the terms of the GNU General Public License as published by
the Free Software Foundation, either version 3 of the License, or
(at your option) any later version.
